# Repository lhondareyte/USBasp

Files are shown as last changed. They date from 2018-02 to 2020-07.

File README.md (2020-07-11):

## USBasp firmware
Latest version of USBasp firmware with TPI support and Green Photon hack for chinese ISP programmers based on ATmega8/48/88.

See [Thomas Fischl's website](https://www.fischl.de/usbasp/) and [Green Photons's blog](https://www.sciencetronics.com/greenphotons/?p=1937) for details.

### Build
Make sure you have avr-gcc toolchain installed. To build the patched version, just type:

`make main.hex`

To build original version, just type:

`make -f Makefile.genuine main.hex`

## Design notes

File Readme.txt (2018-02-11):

This is the README file for USBasp.

USBasp is a USB in-circuit programmer for Atmel AVR controllers. It simply
consists of an ATMega88 or an ATMega8 and a couple of passive components.
The programmer uses a firmware-only USB driver, no special USB controller
is needed.

Features:
- Works under multiple platforms. Linux, Mac OS X and Windows are tested.
- No special controllers or smd components are needed.
- Programming speed is up to 5kBytes/sec.
- SCK option to support targets with low clock speed (< 1,5MHz).
- Planned: serial interface to target (e.g. for debugging).

LICENSE

USBasp is distributed under the terms and conditions of the GNU GPL version
2 (see "firmware/usbdrv/License.txt" for details).

USBasp is built with V-USB driver by OBJECTIVE DEVELOPMENT GmbH. See
"firmware/usbdrv/" for further information.

LIMITATIONS

Hardware:
This package includes a circuit diagram. This circuit can only be used for
programming 5V target systems. For other systems a level converter is needed.

Firmware:
The firmware dosn't support USB Suspend Mode. A bidirectional serial
interface to slave exists in hardware but the firmware doesn't support it yet.

USE PRECOMPILED VERSION

Firmware:
Flash "bin/firmware/usbasp.atmega88.xxxx-xx-xx.hex" or
"bin/firmware/usbasp.atmega8.xxxx-xx-xx.hex" to the used controller with a
working programmer (e.g. with avrdude, uisp, ...). Set jumper J2 to activate
USBasp firmware update function.
You have to change the fuse bits for external crystal (see "make fuses").
# TARGET=atmega8    HFUSE=0xc9  LFUSE=0xef
# TARGET=atmega48   HFUSE=0xdd  LFUSE=0xff
# TARGET=atmega88   HFUSE=0xdd  LFUSE=0xff

Windows:
Start Windows and connect USBasp to the system. When Windows asks for a
driver, choose "bin/win-driver". On Win2k and WinXP systems, Windows will
warn that the driver is is not 'digitally signed'. Ignore this message and
continue with the installation.
Now you can run avrdude. Examples:
1. Enter terminal mode with an AT90S2313 connected to the programmer:
   avrdude -c usbasp -p at90s2313 -t
2. Write main.hex to the flash of an ATmega8:
   avrdude -c usbasp -p atmega8 -U flash:w:main.hex

Setting jumpers:
J1 Power target
   Supply target with 5V (USB voltage). Be careful with this option, the
   circuit isn't protected against short circuit!
J2 Jumper for firmware upgrade (not self-upgradable)
   Set this jumper for flashing the ATMega(4)8 of USBasp with another working
   programmer.
J3 SCK option
   If the target clock is lower than 1,5 MHz, you have to set this jumper.
   Then SCK is scaled down from 375 kHz to about 8 kHz.

BUILDING AND INSTALLING FROM SOURCE CODE

Firmware:
To compile the firmware
1. install the GNU toolchain for AVR microcontrollers (avr-gcc, avr-libc),
2. change directory to firmware/
3. run "make main.hex"
4. flash "main.hex" to the ATMega(4)8. E.g. with uisp or avrdude (check
the Makefile option "make flash"). To flash the firmware you have
to set jumper J2 and connect USBasp to a working programmer.
You have to change the fuse bits for external crystal, (check the Makefile
option "make fuses").

Software (avrdude):
AVRDUDE supports USBasp since version 5.2. 
1. install libusb: http://libusb.sourceforge.net/
2. get latest avrdude release: http://download.savannah.gnu.org/releases/avrdude/
3. cd avrdude-X.X.X
5. configure to your environment:
   ./bootstrap (I had to comment out the two if-blocks which verify the
                installed versions of autoconf and automake)
   ./configure
6. compile and install it:
   make 
   make install

Notes on Windows (Cygwin):
Download libusb-win32-device-bin-x.x.x.x.tar.gz from
http://libusb-win32.sourceforge.net/ and unpack it.
-> copy lib/gcc/libusb.a to lib-path
-> copy include/usb.h to include-path
cd avrdude
./configure LDFLAGS="-static" --enable-versioned-doc=no
make

Notes on Darwin/MacOS X:
after "./configure" I had to edit Makefile:
change "avrdude_CPPFLAGS" to "AM_CPPFLAGS"
(why is this needed only on mac? bug in configure.ac?)

Notes on Linux:
To use USBasp as non-root, you have to define some device rules. See
bin/linux-nonroot for an example.

FILES IN THE DISTRIBUTION

Readme.txt ...................... The file you are currently reading
firmware ........................ Source code of the controller firmware
firmware/usbdrv ................. AVR USB driver by Objective Development
firmware/usbdrv/License.txt ..... Public license for AVR USB driver and USBasp
circuit ......................... Circuit diagram in PDF and EAGLE format
bin ............................. Precompiled programs
bin/win-driver .................. Windows driver
bin/firmware .................... Precompiled firmware
bin/linux-nonroot ............... Linux device rule file

MORE INFORMATION

For more information on USBasp and it's components please visit the
following URLs:

USBasp .......................... http://www.fischl.de/usbasp/

Firmware-only V-USB driver ...... http://www.obdev.at/products/vusb/
avrdude ......................... http://www.nongnu.org/avrdude/
libusb .......................... http://libusb.sourceforge.net/
libusb-win32 .................... http://libusb-win32.sourceforge.net/

2011-05-28 Thomas Fischl <tfischl@gmx.de>
http://www.fischl.de

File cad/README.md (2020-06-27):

## USBasp schematics with 3v3 support

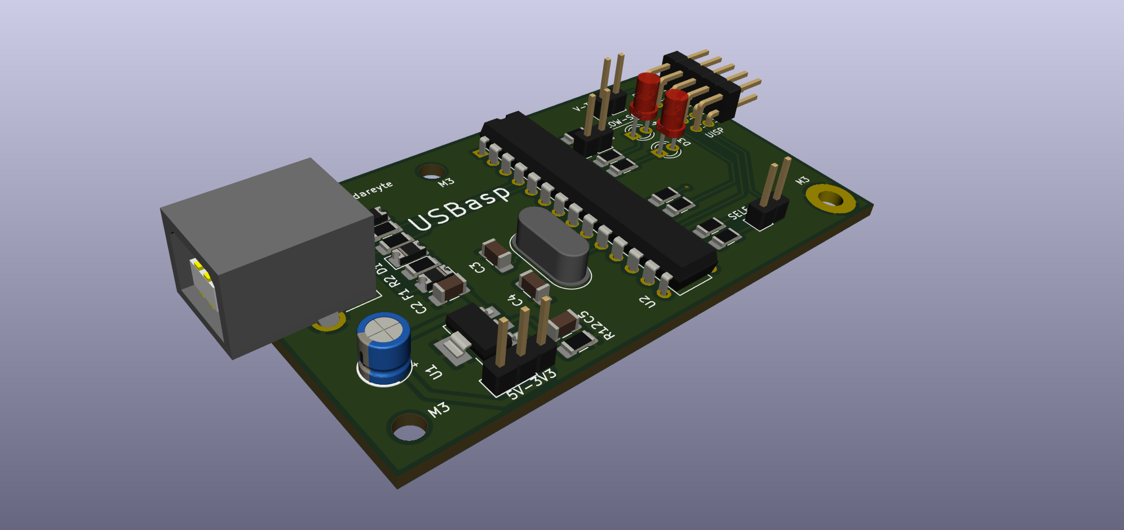
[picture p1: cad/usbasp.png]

* [See here for details](http://lhondareyte.free.fr/wordpress/?p=2791).
* [Thomas Fischl's original schematic](https://www.fischl.de/usbasp/).

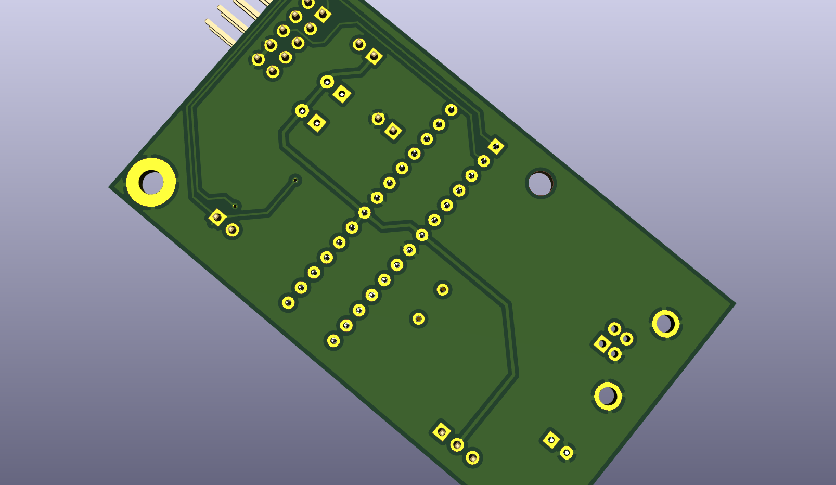
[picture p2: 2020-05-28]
cad/usbasp-b.png

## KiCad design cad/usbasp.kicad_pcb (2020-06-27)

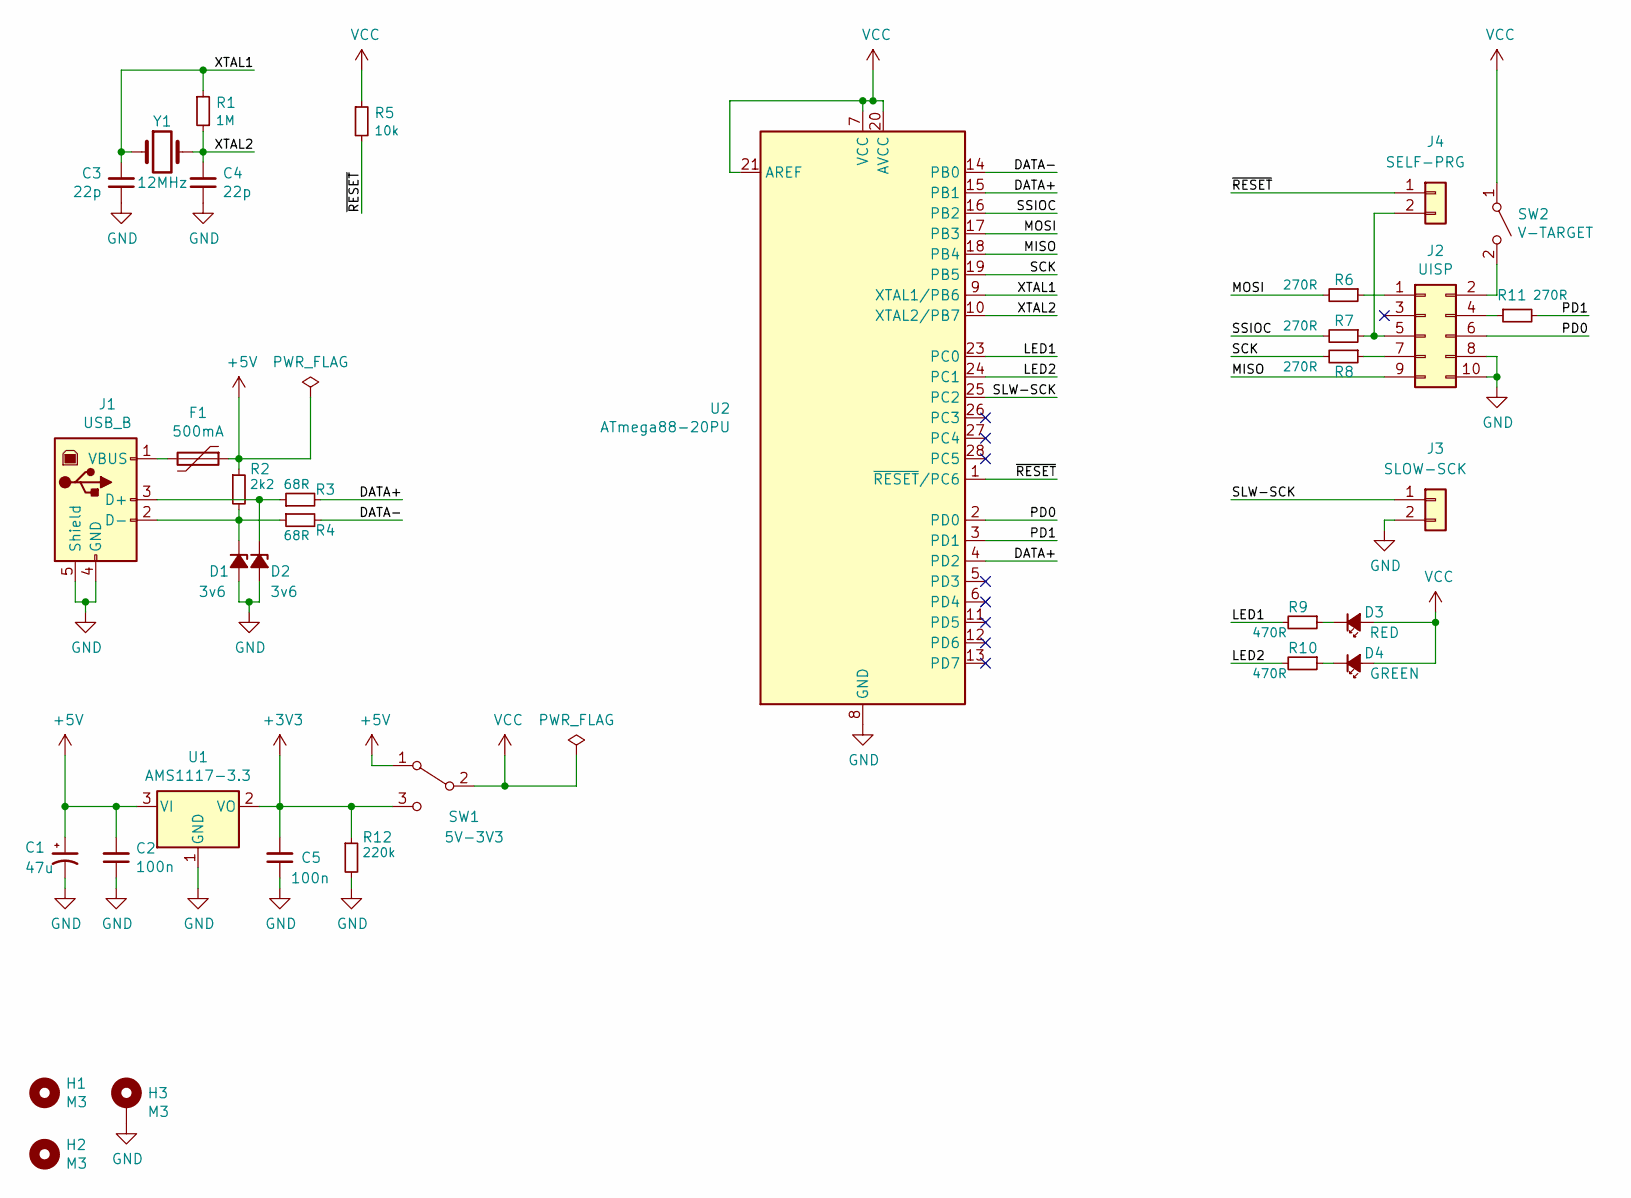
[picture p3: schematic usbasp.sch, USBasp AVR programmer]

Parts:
C1: 47u; CP_Radial_D5.0mm_P2.50mm
C2, C5: 100n; C_1206_3216Metric_Pad1.42x1.75mm_HandSolder
C3, C4: 22p; C_1206_3216Metric_Pad1.42x1.75mm_HandSolder
D1, D2: 3v6; D_1206_3216Metric_Pad1.42x1.75mm_HandSolder
D3: RED; LED_D3.0mm_FlatTop
D4: GREEN; LED_D3.0mm_FlatTop
F1: 500mA; D_1206_3216Metric_Pad1.42x1.75mm_HandSolder
H1, H2: M3; MountingHole_3.2mm_M3
H3: M3; MountingHole_3.2mm_M3_Pad
J1: USB_B; USB_B_OST_USB-B1HSxx_Horizontal
J2: UISP; PinHeader_2x05_P2.54mm_Horizontal
J3: SLOW-SCK; PinHeader_1x02_P2.54mm_Vertical
J4: SELF-PRG; PinHeader_1x02_P2.54mm_Vertical
R1: 1M; R_1206_3216Metric_Pad1.42x1.75mm_HandSolder
R2: 2k2; R_1206_3216Metric_Pad1.42x1.75mm_HandSolder
R3, R4: 68R; R_1206_3216Metric_Pad1.42x1.75mm_HandSolder
R5: 10k; R_1206_3216Metric_Pad1.42x1.75mm_HandSolder
R6, R7, R8, R11: 270R; R_1206_3216Metric_Pad1.42x1.75mm_HandSolder
R9, R10: 470R; R_1206_3216Metric_Pad1.42x1.75mm_HandSolder
R12: 220k; R_1206_3216Metric_Pad1.42x1.75mm_HandSolder
SW1: 5V-3V3; PinHeader_1x03_P2.54mm_Vertical
SW2: V-TARGET; PinHeader_1x02_P2.54mm_Vertical
U1: AMS1117-3.3; SOT-223-3_TabPin2
U2: ATmega88-20PU; DIP-28_W7.62mm
Y1: 12MHz; Crystal_HC49-4H_Vertical

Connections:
+3V3: C5.2, R12.1, SW1.3 (C), U1.2 (VO)
+5V: C1.1, C2.2, F1.1, R2.1, SW1.1 (A), U1.3 (VI)
/DATA+: R3.2, U2.4 (PD2), U2.15 (PB1)
/DATA-: R4.2, U2.14 (PB0)
/LED1: R9.2, U2.23 (PC0)
/LED2: R10.2, U2.24 (PC1)
/MISO: J2.9, U2.18 (PB4)
/MOSI: R6.2, U2.17 (PB3)
/PD0: J2.6, U2.2 (PD0)
/PD1: R11.2, U2.3 (PD1)
/SCK: R8.2, U2.19 (PB5)
/SLW-SCK: J3.1, U2.25 (PC2)
/SSIOC: R7.2, U2.16 (PB2)
/XTAL1: C3.2, R1.1, U2.9 (XTAL1/PB6), Y1.1
/XTAL2: C4.2, R1.2, U2.10 (XTAL2/PB7), Y1.2
/~RESET: J4.1, R5.2, U2.1 (~RESET~/PC6)
GND: C1.2, C2.1, C3.1, C4.1, C5.1, D1.2 (A), D2.2 (A), H3.1, J1.4 (GND), J1.5 (Shield), J2.8, J2.10, J3.2, R12.2, U1.1 (GND), U2.8 (GND), U2.22 (GND)
unnamed: D1.1 (K), J1.2 (D-), R2.2, R4.1
unnamed: D2.1 (K), J1.3 (D+), R3.1
unnamed: D3.1 (K), R9.1
unnamed: D4.1 (K), R10.1
unnamed: F1.2, J1.1 (VBUS)
unnamed: J2.1, R6.1
unnamed: J2.2, SW2.2 (B)
unnamed: J2.4, R11.1
unnamed: J2.5, J4.2, R7.1
unnamed: J2.7, R8.1
VCC: D3.2 (A), D4.2 (A), R5.1, SW1.2 (B), SW2.1 (A), U2.7 (VCC), U2.20 (AVCC), U2.21 (AREF)

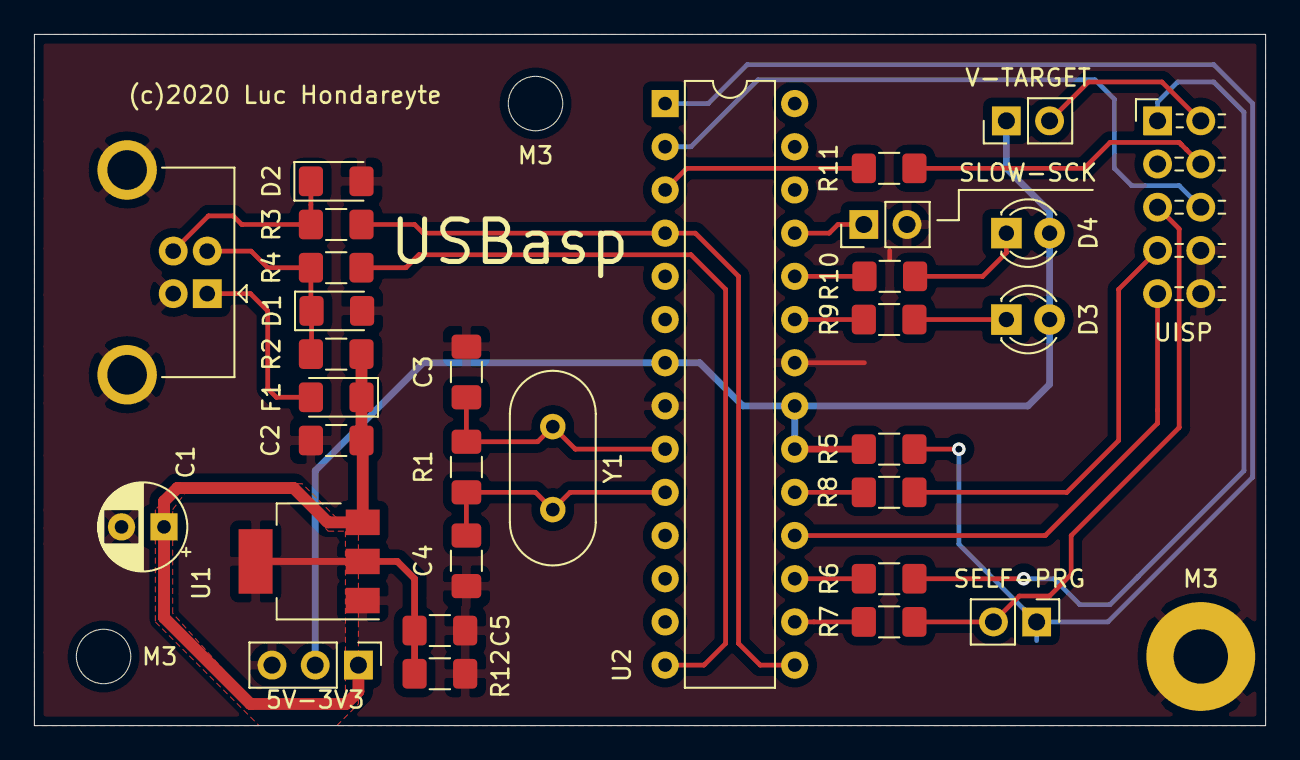
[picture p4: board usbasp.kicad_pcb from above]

Board: 2 copper layers, 72.4 x 40.6 mm, 34 parts (0 on the bottom side), 28 nets.

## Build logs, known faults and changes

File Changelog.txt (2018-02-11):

usbasp.2011-05-28 (v1.4)
------------------------
- added TPI support for ATTiny4/5/6/10 (by Slawomir Fraś)
- added support for controllers with flash >128kb (by Slawomir Fraś)
- fixed resync after program enable signal to pulse RST (based on patch by Marco S)
- updated usb driver to V-USB Release 2010-07-15

usbasp.2009-02-28 (v1.3)
------------------------
- added support for software control of ISP speed (based on patch by Jurgis Brigmanis)
- included new AVRUSB driver version (Release 2008-11-26)
- added libusb 0.1.12.1 windows drivers (needed for WinAVR version 20080512 or greater)

usbasp.2007-10-23 (v1.2)
------------------------
- red LED turns on before connecting to target device: this signal can be used to control external tri-state buffers (by Pawel Szramowski)

usbasp.2007-07-23
-----------------
- changed licence to GNU GPL v2
- included new AVRUSB driver version (Release 2007-07-07); AVRUSB licence was changed to GNU GPL v2
- fixed long addressing for Mega128 (by BoskiDialer)

usbasp.2006-12-29
-----------------
- fixed returnvalue in usbWriteFunction (by Jeroen Koeter)
- changed clock.h: adaptation for newer MCUs like ATMega48 (by Hanns-Konrad Unger)
- improved Makefile to select target (by Hanns-Konrad Unger)
- circuit diagram: added zener diodes to USB data lines 

usbasp.2006-09-16
-----------------
- add usb reset on startup
- included new AVRUSB driver version (Release 2006-07-18)
- changed VID and PID to OBDEV's shared IDs to meet new licence conditions
- removed avrdude patch from this package. USBasp is supported in latest avrdude CVS version 

usbasp.2005-11-14
-----------------
- fixed blocksize restriction (programming the Mega128 now works) 
  by Thomas Pfeifer (TP)
- update patch for avrdude-5.0

usbasp.2005-07-03
-----------------
- set USB_CFG_SAMPLE_EXACT in usbconfig.h to reduce problems with long cables
- corrected vendor string
- added notes on setting fuse bits

usbasp.2005-04-21
-----------------
- first public version

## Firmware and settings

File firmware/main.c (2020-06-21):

/*
 * USBasp - USB in-circuit programmer for Atmel AVR controllers
 *
 * Thomas Fischl <tfischl@gmx.de>
 *
 * License........: GNU GPL v2 (see Readme.txt)
 * Target.........: ATMega8 at 12 MHz
 * Creation Date..: 2005-02-20
 * Last change....: 2009-02-28
 *
 * PC2 SCK speed option.
 * GND  -> slow (8khz SCK),
 * open -> software set speed (default is 375kHz SCK)
 */

#include <avr/io.h>
#include <avr/interrupt.h>
#include <avr/pgmspace.h>
#include <avr/wdt.h>

#include "usbasp.h"
#include "usbdrv.h"
#include "isp.h"
#include "clock.h"
#include "tpi.h"
#include "tpi_defs.h"

static uchar replyBuffer[8];

static uchar prog_state = PROG_STATE_IDLE;
static uchar prog_sck = USBASP_ISP_SCK_AUTO;

static uchar prog_address_newmode = 0;
static unsigned long prog_address;
static unsigned int prog_nbytes = 0;
static unsigned int prog_pagesize;
static uchar prog_blockflags;
static uchar prog_pagecounter;

uchar usbFunctionSetup(uchar data[8]) {

	uchar len = 0;

	if (data[1] == USBASP_FUNC_CONNECT) {

		/* set SCK speed */
		if ((PINC & (1 << PC2)) == 0) {
			ispSetSCKOption(USBASP_ISP_SCK_8);
		} else {
			ispSetSCKOption(prog_sck);
		}

		/* set compatibility mode of address delivering */
		prog_address_newmode = 0;

		ledRedOn();
		ispConnect();

	} else if (data[1] == USBASP_FUNC_DISCONNECT) {
		ispDisconnect();
		ledRedOff();

	} else if (data[1] == USBASP_FUNC_TRANSMIT) {
		replyBuffer[0] = ispTransmit(data[2]);
		replyBuffer[1] = ispTransmit(data[3]);
		replyBuffer[2] = ispTransmit(data[4]);
		replyBuffer[3] = ispTransmit(data[5]);
		len = 4;

	} else if (data[1] == USBASP_FUNC_READFLASH) {

		if (!prog_address_newmode)
			prog_address = (data[3] << 8) | data[2];

		prog_nbytes = (data[7] << 8) | data[6];
		prog_state = PROG_STATE_READFLASH;
		len = 0xff; /* multiple in */

	} else if (data[1] == USBASP_FUNC_READEEPROM) {

		if (!prog_address_newmode)
			prog_address = (data[3] << 8) | data[2];

		prog_nbytes = (data[7] << 8) | data[6];
		prog_state = PROG_STATE_READEEPROM;
		len = 0xff; /* multiple in */

	} else if (data[1] == USBASP_FUNC_ENABLEPROG) {
		replyBuffer[0] = ispEnterProgrammingMode();
		len = 1;

	} else if (data[1] == USBASP_FUNC_WRITEFLASH) {

		if (!prog_address_newmode)
			prog_address = (data[3] << 8) | data[2];

		prog_pagesize = data[4];
		prog_blockflags = data[5] & 0x0F;
		prog_pagesize += (((unsigned int) data[5] & 0xF0) << 4);
		if (prog_blockflags & PROG_BLOCKFLAG_FIRST) {
			prog_pagecounter = prog_pagesize;
		}
		prog_nbytes = (data[7] << 8) | data[6];
		prog_state = PROG_STATE_WRITEFLASH;
		len = 0xff; /* multiple out */

	} else if (data[1] == USBASP_FUNC_WRITEEEPROM) {

		if (!prog_address_newmode)
			prog_address = (data[3] << 8) | data[2];

		prog_pagesize = 0;
		prog_blockflags = 0;
		prog_nbytes = (data[7] << 8) | data[6];
		prog_state = PROG_STATE_WRITEEEPROM;
		len = 0xff; /* multiple out */

	} else if (data[1] == USBASP_FUNC_SETLONGADDRESS) {

		/* set new mode of address delivering (ignore address delivered in commands) */
		prog_address_newmode = 1;
		/* set new address */
		prog_address = *((unsigned long*) &data[2]);

	} else if (data[1] == USBASP_FUNC_SETISPSCK) {

		/* set sck option */
		prog_sck = data[2];
		replyBuffer[0] = 0;
		len = 1;

	} else if (data[1] == USBASP_FUNC_TPI_CONNECT) {
		tpi_dly_cnt = data[2] | (data[3] << 8);

		/* RST high */
		ISP_OUT |= (1 << ISP_RST);
		ISP_DDR |= (1 << ISP_RST);

		clockWait(3);

		/* RST low */
		ISP_OUT &= ~(1 << ISP_RST);
		ledRedOn();

		clockWait(16);
		tpi_init();
	
	} else if (data[1] == USBASP_FUNC_TPI_DISCONNECT) {

		tpi_send_byte(TPI_OP_SSTCS(TPISR));
		tpi_send_byte(0);

		clockWait(10);

		/* pulse RST */
		ISP_OUT |= (1 << ISP_RST);
		clockWait(5);
		ISP_OUT &= ~(1 << ISP_RST);
		clockWait(5);

		/* set all ISP pins inputs */
		ISP_DDR &= ~((1 << ISP_RST) | (1 << ISP_SCK) | (1 << ISP_MOSI));
		/* switch pullups off */
		ISP_OUT &= ~((1 << ISP_RST) | (1 << ISP_SCK) | (1 << ISP_MOSI));

		ledRedOff();
	
	} else if (data[1] == USBASP_FUNC_TPI_RAWREAD) {
		replyBuffer[0] = tpi_recv_byte();
		len = 1;
	
	} else if (data[1] == USBASP_FUNC_TPI_RAWWRITE) {
		tpi_send_byte(data[2]);
	
	} else if (data[1] == USBASP_FUNC_TPI_READBLOCK) {
		prog_address = (data[3] << 8) | data[2];
		prog_nbytes = (data[7] << 8) | data[6];
		prog_state = PROG_STATE_TPI_READ;
		len = 0xff; /* multiple in */
	
	} else if (data[1] == USBASP_FUNC_TPI_WRITEBLOCK) {
		prog_address = (data[3] << 8) | data[2];
		prog_nbytes = (data[7] << 8) | data[6];
		prog_state = PROG_STATE_TPI_WRITE;
		len = 0xff; /* multiple out */
	
	} else if (data[1] == USBASP_FUNC_GETCAPABILITIES) {
		replyBuffer[0] = USBASP_CAP_0_TPI;
		replyBuffer[1] = 0;
		replyBuffer[2] = 0;
		replyBuffer[3] = 0;
		len = 4;
	}

	usbMsgPtr = replyBuffer;

	return len;
}

uchar usbFunctionRead(uchar *data, uchar len) {

	uchar i;

	/* check if programmer is in correct read state */
	if ((prog_state != PROG_STATE_READFLASH) && (prog_state
			!= PROG_STATE_READEEPROM) && (prog_state != PROG_STATE_TPI_READ)) {
		return 0xff;
	}

	/* fill packet TPI mode */
	if(prog_state == PROG_STATE_TPI_READ)
	{
		tpi_read_block(prog_address, data, len);
		prog_address += len;
		return len;
	}

	/* fill packet ISP mode */
	for (i = 0; i < len; i++) {
		if (prog_state == PROG_STATE_READFLASH) {
			data[i] = ispReadFlash(prog_address);
		} else {
			data[i] = ispReadEEPROM(prog_address);
		}
		prog_address++;
	}

	/* last packet? */
	if (len < 8) {
		prog_state = PROG_STATE_IDLE;
	}

	return len;
}

uchar usbFunctionWrite(uchar *data, uchar len) {

	uchar retVal = 0;
	uchar i;

	/* check if programmer is in correct write state */
	if ((prog_state != PROG_STATE_WRITEFLASH) && (prog_state
			!= PROG_STATE_WRITEEEPROM) && (prog_state != PROG_STATE_TPI_WRITE)) {
		return 0xff;
	}

	if (prog_state == PROG_STATE_TPI_WRITE)
	{
		tpi_write_block(prog_address, data, len);
		prog_address += len;
		prog_nbytes -= len;
		if(prog_nbytes <= 0)
		{
			prog_state = PROG_STATE_IDLE;
			return 1;
		}
		return 0;
	}

	for (i = 0; i < len; i++) {

		if (prog_state == PROG_STATE_WRITEFLASH) {
			/* Flash */

			if (prog_pagesize == 0) {
				/* not paged */
				ispWriteFlash(prog_address, data[i], 1);
			} else {
				/* paged */
				ispWriteFlash(prog_address, data[i], 0);
				prog_pagecounter--;
				if (prog_pagecounter == 0) {
					ispFlushPage(prog_address, data[i]);
					prog_pagecounter = prog_pagesize;
				}
			}

		} else {
			/* EEPROM */
			ispWriteEEPROM(prog_address, data[i]);
		}

		prog_nbytes--;

		if (prog_nbytes == 0) {
			prog_state = PROG_STATE_IDLE;
			if ((prog_blockflags & PROG_BLOCKFLAG_LAST) && (prog_pagecounter
					!= prog_pagesize)) {

				/* last block and page flush pending, so flush it now */
				ispFlushPage(prog_address, data[i]);
			}

			retVal = 1; // Need to return 1 when no more data is to be received
		}

		prog_address++;
	}

	return retVal;
}

int main(void) {
	uchar i, j;

	/* no pullups on USB and ISP pins */
	PORTD = 0;
	PORTB = 0;
#if defined (__GREEN_PHOTONS__)
	DDRD = 0x00;
#else
	/* all outputs except PD2 = INT0 */
	DDRD = ~(1 << 2);
#endif

	/* output SE0 for USB reset */
	DDRB = ~0;
	j = 0;
	/* USB Reset by device only required on Watchdog Reset */
	while (--j) {
		i = 0;
		/* delay >10ms for USB reset */
		while (--i)
			;
	}
	/* all USB and ISP pins inputs */
	DDRB = 0;

	/* all inputs except PC0, PC1 */
	DDRC = 0x03;
	PORTC = 0xfe;

	/* init timer */
	clockInit();

	/* main event loop */
	usbInit();
	sei();
	for (;;) {
		usbPoll();
	}
	return 0;
}

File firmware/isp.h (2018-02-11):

/*
 * isp.h - part of USBasp
 *
 * Autor..........: Thomas Fischl <tfischl@gmx.de>
 * Description....: Provides functions for communication/programming
 *                  over ISP interface
 * Licence........: GNU GPL v2 (see Readme.txt)
 * Creation Date..: 2005-02-23
 * Last change....: 2009-02-28
 */

#ifndef __isp_h_included__
#define	__isp_h_included__

#ifndef uchar
#define	uchar	unsigned char
#endif

#define	ISP_OUT   PORTB
#define ISP_IN    PINB
#define ISP_DDR   DDRB
#define ISP_RST   PB2
#define ISP_MOSI  PB3
#define ISP_MISO  PB4
#define ISP_SCK   PB5

/* Prepare connection to target device */
void ispConnect();

/* Close connection to target device */
void ispDisconnect();

/* read an write a byte from isp using software (slow) */
uchar ispTransmit_sw(uchar send_byte);

/* read an write a byte from isp using hardware (fast) */
uchar ispTransmit_hw(uchar send_byte);

/* enter programming mode */
uchar ispEnterProgrammingMode();

/* read byte from eeprom at given address */
uchar ispReadEEPROM(unsigned int address);

/* write byte to flash at given address */
uchar ispWriteFlash(unsigned long address, uchar data, uchar pollmode);

uchar ispFlushPage(unsigned long address, uchar pollvalue);

/* read byte from flash at given address */
uchar ispReadFlash(unsigned long address);

/* write byte to eeprom at given address */
uchar ispWriteEEPROM(unsigned int address, uchar data);

/* pointer to sw or hw transmit function */
uchar (*ispTransmit)(uchar);

/* set SCK speed. call before ispConnect! */
void ispSetSCKOption(uchar sckoption);

/* load extended address byte */
void ispLoadExtendedAddressByte(unsigned long address);

#endif /* __isp_h_included__ */

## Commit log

2018-02-11 Add Green Photons workaround.
    [main.c]
2020-05-09 Adding KiCad schematic.
    [usbasp.kicad_pcb, usbasp.sch]
2020-05-28 Schematic: add 3.3v support
    [usbasp-B_Cu.gbr, usbasp-B_Mask.gbr, usbasp-B_Paste.gbr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]
2020-06-27 cad: update USB connector 3D model.
    [usbasp.kicad_pcb]

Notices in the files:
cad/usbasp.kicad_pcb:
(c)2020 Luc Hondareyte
